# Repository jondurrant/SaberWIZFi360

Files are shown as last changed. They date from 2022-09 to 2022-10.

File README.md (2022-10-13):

# SaberWIZFi360
IoT Saber Wall Light using WizFi360-EVB-Pico

PIR and Switch activated wall light. Works as a group able to turn each other on and off via MQTT hub topics. 

Blog post and video talking about project coming soon.

# Hardware

+ WizFi360-EVB-Pico: RP2040 board with Wifi adapter for connectivity and control
+ 144, 1M WS2812B: The LED used to illuminate and animate the blade
+ Logic Level Shifter: Used to drive 5V signal to WS2812B
+ 1000uF Capacitor: Smooth out supply for the WS2812B strip
+ 330Ω Resistor: Signal connection to the WS2812B strip
+ 4x 75Ω (or 91Ω) Resistors for onboard LEDs
+ SPST Non-latching Switch: For turn on or off the blade
+ AM312: Small PIR sensor module
+ 100nF Cap: Power smoothing for the AM312 to prevent false detects
+ 100uF Cap: Power smoothing for the AM312 to prevent false detects
+ 5Amp Fuse and Holder: Main power fuse
+ 100℃ Thermal Fuse: Main power thermal fuse
+ RGB 5mm LED - To use as signal LED
+ Red 1.8mm LED - to use as a pulse LED against the device
+ 6V >5Amp Power Suppl
+ 1m White Acrylic 20mm Tube: The blade cover tube. White so it is diffusing the light
+ 3D Printed Parts: Handle and pommel are 3D printed

## Schema 
Schematic included in the schematic folder.

Warning: The LEDs will draw 4Amps of current. You should assure yourself that the circuit and wiring can safely deliver that current. 

## Case
Case is 3D printed in PLA. I've modelled the case and wall mounts for the case in OpenSCAD. The model and SLA files available in the 3dmodels folder.

## Blade
Blade is a 20mm x 3mm x 1000mm OPAL Acrylic Tube. You can find these on ebay, though I found ebay quite expensive. Bought mine from [The Clear Plastic Shop](https://clearplastictube.co.uk/opal-acrylic-tube) in the UK. 

# Software

## C++ - For Raspberry PICO
+ [CMSIS_5](https://github.com/ARM-software/CMSIS_5.git) - RELEASE 5.8.0 CMSIS Framework
+ [CMSIS-FreeRTOS]https://github.com/ARM-software/CMSIS-FreeRTOS.git() - RELEASE 10.5.6 CMSIS port of FreeRTOS
+ [CMSIS-Driver](https://github.com/ARM-software/CMSIS-Driver.git) - RELEASE 2.70 WizFi360 Driver
+ [IoT_Socket](https://github.com/MDK-Packs/IoT_Socket.git) - RELEASE 1.3.0 Socket framework
+ [coreMQTT](https://github.com/FreeRTOS/coreMQTT) - RELEASE 1.2.0 FreeRTOS MQTT library
+ [coreMQTT-Agent](https://github.com/FreeRTOS/coreMQTT-Agent) - FreeRTOS MQTT Agent library, using FreeRTOS tasks
+ [twinThingWizFi360](https://github.com/jondurrant/twinThingWizFi360) - Digital Twin library
+ [json-make](https://github.com/rafagafe/json-maker) - JSON creation used for the payload of all MQTT messages
+ [tiny-json](https://github.com/rafagafe/tiny-json) - JSON parser used for the payload parsing of all MQTT messages
+ [PicoLED](https://github.com/ForsakenNGS/PicoLED) - Used to drive the WS2812B LED via PIO

## Python -  Management Software
See the [LSaber1 project](https://github.com/jondurrant/LSaber1).

## Python Test Code
Some test code to interact with the api are included in py/test folder. They expect some environment variables to point to the MQTT hub and credentials.
+ MQTT_USER - Username and Client Id to connect to MQTT
+ MQTT_PASSWD - Password to authenticate against MQTT
+ MQTT_HOST - Hostname of MQTT server
+ MQTT_PORT - Port that MQTT is listen on, normally 1883

# Build and Deploy

##Clone project
```
git clone --recurse-submodules https://github.com/jondurrant/SaberWIZFi360
```
main.cpp include "Credentials.env" for the Wifi AP name and passwd, MQTT Host, Port, Username and password. I've not included this file in the repo. Please create one looking something like this:

``` C++
#define SID "SID"
#define PASSWD "PWD"

#define MQTTHOST "IP"
#define MQTTPORT 1883
#define MQTTUSER "jon"
#define MQTTPASSWD "PWD"
```

## To build C++:
``` bash
mkdir build
cd build
cmake ..
make
```

# Plug

For more on how I use a Raspberry PI to build, deploy code  and debug the Pico see my course on [Udemy](https://www.udemy.com/course/introduction-to-c-development-environment-for-raspberry-pico/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)

For more on FreeRTOS kernel development with the Pico or Pico W please see my course on [Udemy](https://www.udemy.com/course/freertos-on-rpi-pico/?referralCode=C5A9A19C93919A9DA294)

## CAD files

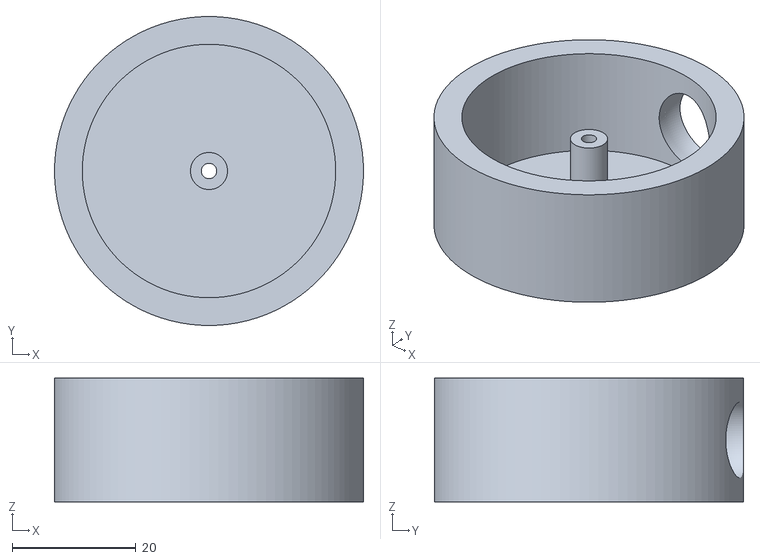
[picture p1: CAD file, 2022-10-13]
3dmodels/pummel.stl
50.0 x 50.0 x 20.0

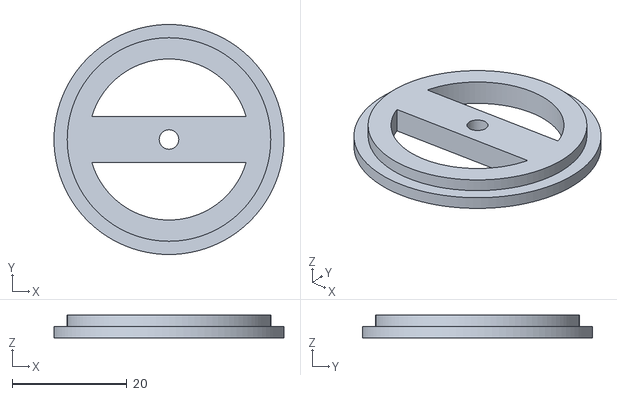
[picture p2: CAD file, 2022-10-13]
3dmodels/pummelInt.stl
40.0 x 40.0 x 4.00

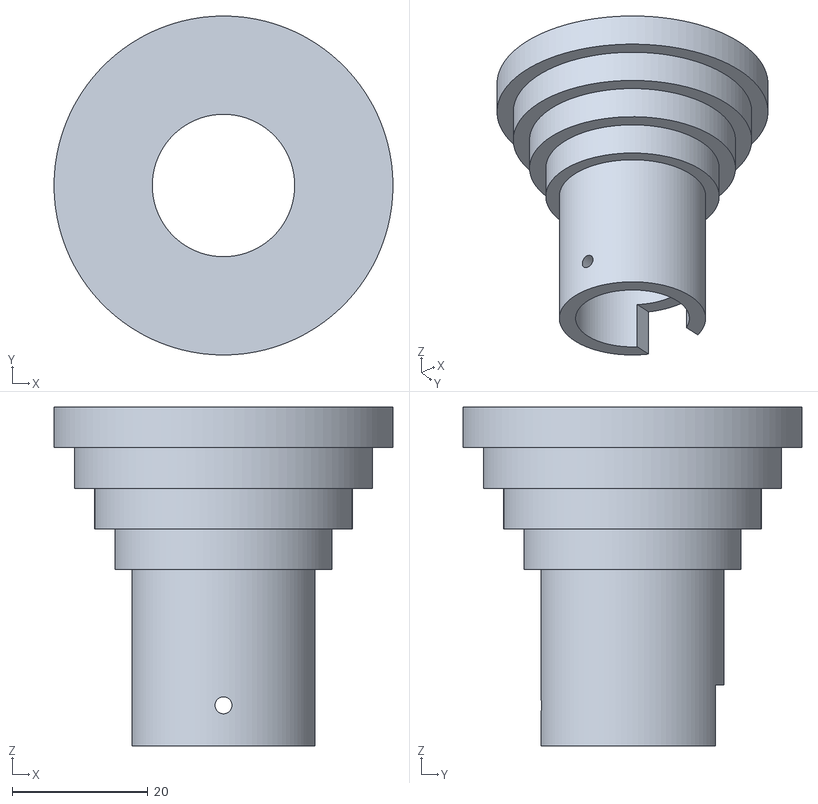
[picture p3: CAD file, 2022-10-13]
3dmodels/stem.stl
50.0 x 50.0 x 50.0

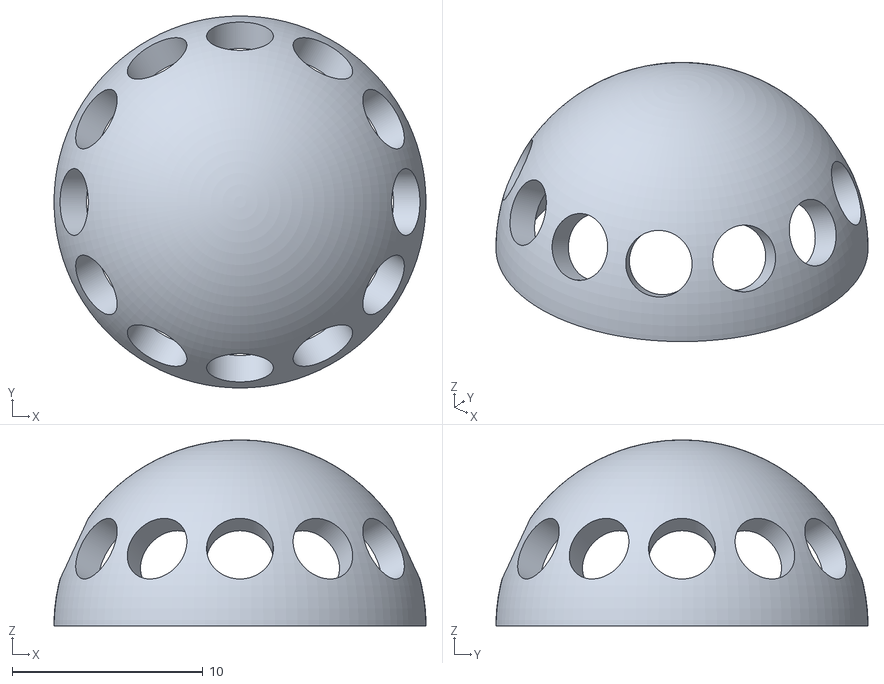
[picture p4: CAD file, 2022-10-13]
3dmodels/cap.stl
19.5 x 19.5 x 9.75

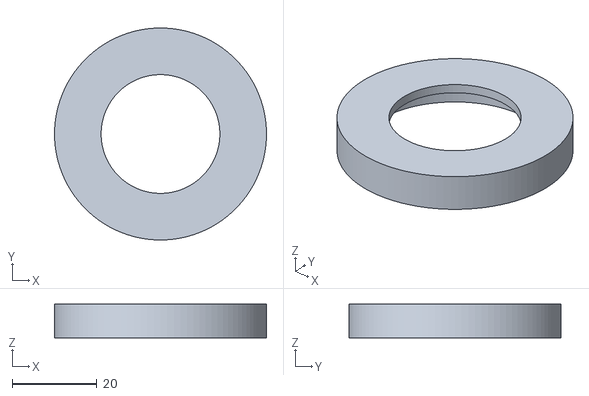
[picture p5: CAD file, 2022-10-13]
3dmodels/guardShort.stl
50.0 x 50.0 x 8.00

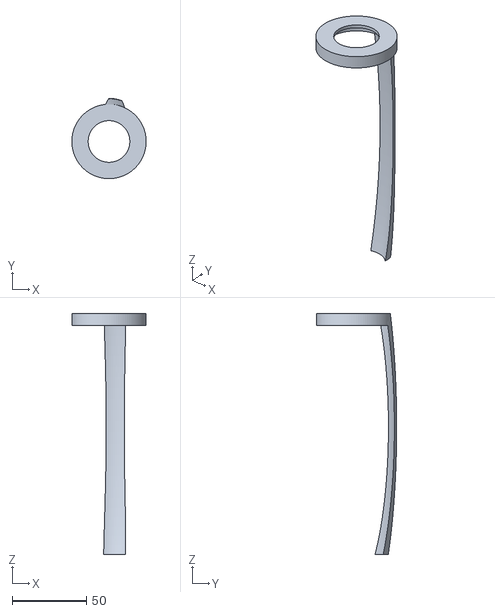
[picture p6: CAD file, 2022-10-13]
3dmodels/guard.stl
50.0 x 54.0 x 162.0

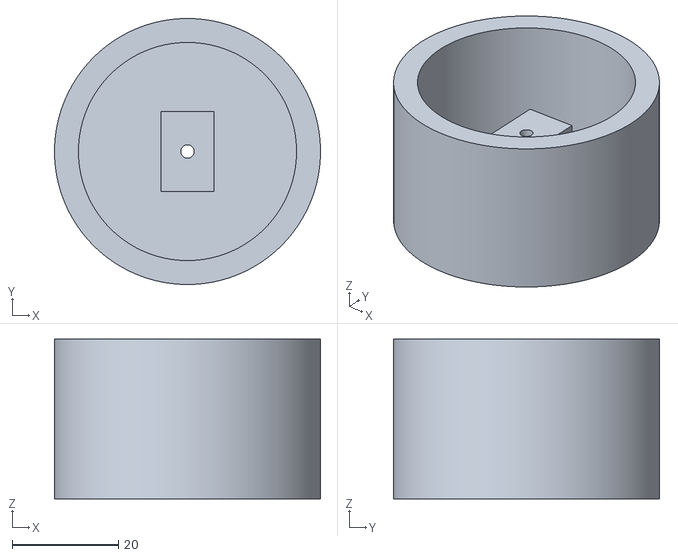
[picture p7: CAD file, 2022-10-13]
3dmodels/pummelHBS.stl
50.0 x 50.0 x 30.0

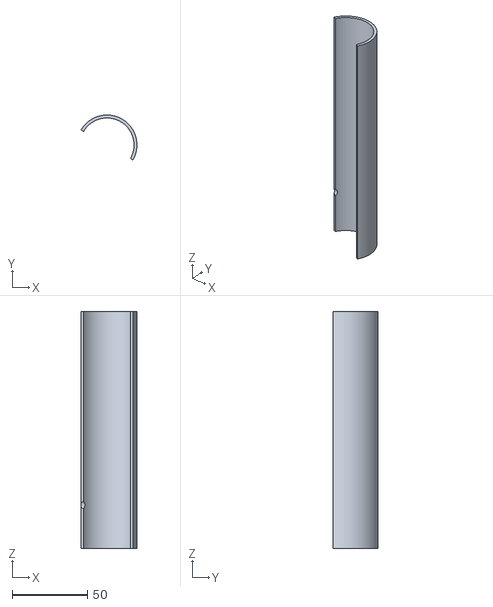
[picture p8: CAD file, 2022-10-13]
3dmodels/gripRear.stl
37.3 x 30.0 x 158.0

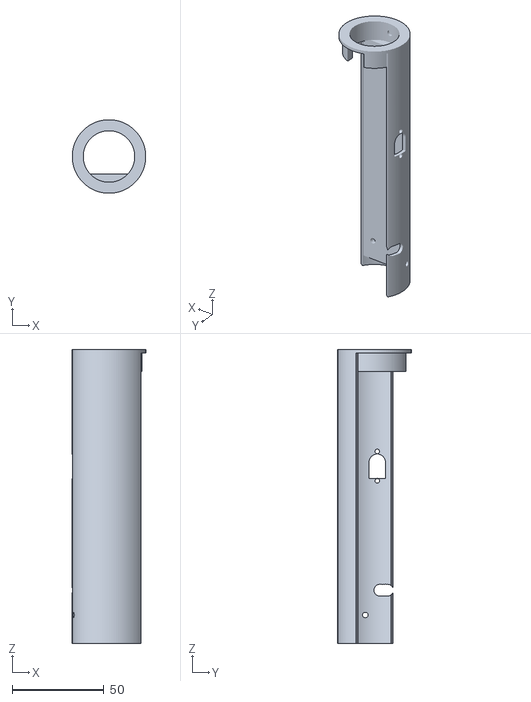
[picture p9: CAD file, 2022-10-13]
3dmodels/gripBack.stl
40.0 x 40.0 x 160.0

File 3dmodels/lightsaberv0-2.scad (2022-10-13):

//Fixings
M5=5.5;
M4=4.5;
M3=3.5;
M2=2.5;
M3INSERT=3.7;
M2INSERT=3.4;


//Blade
BladeDiam=23;//24;
BladeDiamTrue=19.5;
BladeLen=100; //Debug only
BladeThick=3;

CapCollar=2;

//Pico
PicoWid=21;
PicoLen=64;
PicoDep=19;

//PIZ
PIZWid=34;
PIZLen=72;
PIZDep=19;
PCBGrid=2.54;

//Stem
StemLen=50;
StemCollar=0;//5;
StemSegLen=6;
StemSegMaxDiam=50;
StemSegStep=6;

//Grip
GripLen=160; //Max print size is 170
GripDiam=40;//45;
GripOverlap=12;

//Pummel
PummelDiam=GripDiam+10;
PummelIntDiam = GripDiam + 1;
PummelLen=20;
PummelHBSLen=30;
PummelOverlap=5;
PowerWid=11.5;
PowerLen=9;


//PCB
PCBWidth=30.5;
PCBLen=135;
PCBBRy=3.9;
PCBBRx=7.35;
PCBBLx=16.51;//15.51;
PCBBLy=9.4;
PCBTRx=0;
PCBTRy=90.79;
PCBLEDy=12.5;
PCBLEDx=10;
PCBLEDz=5;
PCBSwitchD=5 ;
PCBSwitchY=23.5;
PCBSwitchX=7.6;
PCBSwitchZ=15;//12;
PCBSwitchL=20;
PCBCapX=12;
PCBCapY=114;
PCBCapL=20;
PCBCapZ=PCBCapL/2;
PCBCapD=10.2;
PCBOffz=10;
PCBOffy=-10;



THICK=2;

$fn=200;


/*
Blade();
Pico();
PIZ();
*/
//Blade();
//PCB();
//PIR();

    
//BladeCap();

//Stem();
//GripBack();
//PummelInt();
//Pummel();
PummelHBS();
//translate([5,10,0]) GripFront();
//GripFront();

//Guard();
//GuardShort();

//MountBottom();
//MountTop();



//Test print
/*
difference(){
    GripBack();
    translate([0,0,GripLen*(-0.85)])
        cube([PummelDiam, PummelDiam, GripLen], center=true);
}
*/




module Blade(){
    color("blue")
    translate([0,0,BladeLen/2]){
        difference(){
            cylinder(d=BladeDiam, h=BladeLen, center=true);
            cylinder(d=BladeDiam-(BladeThick*2), h=BladeLen+10, center=true);
        }
        
    }
}

module BladeCap(){
    inner = BladeDiamTrue-(BladeThick);
    translate([0,0,BladeLen]){
        //Half hollow Sphere
        difference(){
            sphere(d=BladeDiamTrue, $fn=100);
            sphere(d=inner);
            translate([0,0,BladeDiamTrue/(-2)]){
                cube([BladeDiamTrue+10, BladeDiamTrue+10, BladeDiamTrue], center=true);
            }
            
            
           for (x=[0:30:360]){
               rotate([0,0,x]){
                   rotate([0,65,0])
                      cylinder(d=M3, h=BladeThick*10, center=true);
               }
           }
  
            
        }
        //Connection collar
        /*
        difference(){
            cylinder(d=inner, h=CapCollar*2, center=true);
            cylinder(d=inner-(THICK*2), h=CapCollar*4, center=true);
        }
        */
    }
}

module Stem(){
    //Inner Tube
    translate([0,0,StemLen/(-2)]){
        difference(){
            cylinder(d=BladeDiam+(THICK*2), h=StemLen, center=true);
            cylinder(d=BladeDiam-(THICK), h=StemLen+10, center=true);
            translate([0,0,(StemLen/2)-(StemCollar/2)]){
                cylinder(d=BladeDiam, h=StemCollar, center=true);
            }
            
            //Coupline
            CoupZ=StemLen/(-2) + (GripOverlap/2);
            translate([0, 0, CoupZ]){
                //Hole
                rotate([90,0,0]){
                    cylinder(d=M2, h=BladeDiam+(THICK*4), center=true);
                }
                //Loose top
                translate([0, (BladeDiam+(THICK*2))/2, THICK*(-1)]){
                    //cube([BladeDiam+(THICK*2), BladeDiam+(THICK*2), GripOverlap-THICK], center=true);
                    cube([BladeDiam/2, BladeDiam+(THICK*2), GripOverlap-THICK], center=true);
                }
            }
        }
    }
    //Steps
    difference(){
        translate([0,0,StemSegLen/2]){
            for(i=[0:4]){
                translate([0, 0, (StemSegLen*(i+1))/(-1)]){
                    cylinder(d=StemSegMaxDiam-(StemSegStep*i), h=StemSegLen, center=true);
                }
            }
        }
        //Hole
        translate([0,0,StemLen/(-2)]){
            cylinder(d=BladeDiam, h=StemLen+10, center=true);
        }   
    }
}

function picoZ()=(StemLen + ((PicoLen+(THICK*4)) / (2)))* (-1) ;

module Pico(){
    z=picoZ();
    translate([0,0,z]){
        color("lightgrey"){
            cube([PicoWid, PicoDep, PicoLen], center=true);
        }
    }
}

module PIZ(){
    z=picoZ() - PIZLen ;
    translate([0,0,z]){
        color("lightGreen"){
            cube([PIZWid, PIZDep, PIZLen], center=true);
        }
    }
}


module GripBack(){
    difference(){
        GripTube();
        rotate([0,0,-30]){
            translate([0,GripDiam/2, gripTubeZ()-THICK]){
                cube([GripDiam+10,GripDiam,GripLen ], center=true);
            }
        }
    }
    stemCoupling();
}

module GripFront(){
    intersection(){
        difference(){
            GripTube();
            translate([0,0,gripTubeZ()]){
                cylinder(d=GripDiam - (THICK*2), h=GripLen+10, center=true);
            }
            rotate([0, 0, -30]){
                translate([0,GripDiam/(-2), gripTubeZ()]){
                    cube([GripDiam+10,GripDiam,GripLen+10 ], center=true);
                }
            }
            
            /*
            //Switch hole
            translate([0,PCBOffy,gripTubeZ()]){
                for(i=[-2:1:2]){
                    translate([PCBWidth/-2, PCBSwitchZ + i, PCBLen/-2-5.5+PCBSwitchY]){
                        rotate([0,90,0]){
                            cylinder(d=PCBSwitchD+1,h=20,center=true);
                        }
                    }
                }
            }
            */
        }
        
        rotate([0, 0, -30]){
            translate([0,GripDiam/2, gripTubeZ()-THICK]){
                cube([GripDiam+10,GripDiam,GripLen ], center=true);
            }
        }
    }
}
    
function gripTubeZ() = (StemLen + GripLen/2 - GripOverlap) *( -1);
module GripTube(){
    z=gripTubeZ();
    translate([0,0,z]){
        difference(){
            cylinder(d=GripDiam, h=GripLen, center=true);
            translate([0,0,THICK*(-1)]){
                cylinder(d=GripDiam - (THICK*2), h=GripLen, center=true);
            }
            //Stem Hole
            cylinder(d=BladeDiam+(THICK*2.5), h=GripLen+10, center=true);
            
            //LED hole
            translate([PCBWidth/-2, PCBLEDz*(-1), PCBLen/-2-9.5+PCBLEDy]){
                rotate([0,90,0]){
                    cylinder(d=3,h=20,center=true);
                }
            }
            
            //Switch hole
            translate([PCBWidth/-2, PCBSwitchZ+PCBOffy, PCBLen/-2-7+PCBSwitchY]){
                for(i=[-2:1:2]){
                    translate([0, i, 0]){
                        rotate([0,90,0]){
                            cylinder(d=PCBSwitchD+1.5,h=20,center=true);
                        }
                    }
                }
            }
            
            //PowerHole
            translate([PCBWidth/-2, -4.5, PCBLen/2-5]){
                translate([-5, 0, PowerSocketY*(-1)]){
                    rotate([90,0,0])
                        PowerSocketHole();
                }
            }
        }
    }
    
    stemCoupling();
    
    
    //PCB Mount
    translate([0,0,z-(GripOverlap/2)]){
        difference(){
            //PCB plate
            cylinder(d=GripDiam, h=GripLen-(GripOverlap), center=true);
            cube([GripDiam, PIZDep, GripLen], center=true);
            translate([0,GripDiam/2,0]){
                cube([GripDiam+10, GripDiam, GripLen+10], center=true);
            }
            translate([0,0,PCBLen/(-2)-5]){
                cube([GripDiam, GripDiam, 10], center=true);
            }
            
            //Mounting Holes
            translate([PCBWidth/-2,0, PCBLen/-2-1.5]){
                translate([PCBBRx,0,PCBBRy]){
                    rotate([90,0,0]){
                        cylinder(d=M2INSERT, h=BladeDiam+(THICK*4), center=true);
                    }
                    translate([PCBBLx,0, PCBBLy]){
                        rotate([90,0,0]){
                            cylinder(d=M2INSERT, h=BladeDiam+(THICK*4), center=true);
                        }
                    }
                    translate([PCBTRx,0, PCBTRy]){
                       rotate([90,0,0]){
                            cylinder(d=M2INSERT, h=BladeDiam+(THICK*4), center=true);
                        }
                    }
                }
            }
            
            
            /*
            //PCB Weight Holes
            pcbCountX=GripDiam/PCBGrid/2-2;
            pcbCountY=(GripLen-GripOverlap)/PCBGrid/2;
            for (y=[0:5:pcbCountY]){
                for (j=[-1,1]){
                    translate([0, 0, y*j*PCBGrid]){
                        for (x=[0:3:pcbCountX]){
                            for (i=[-1,1]){
                                translate([x*i*PCBGrid,0,0]){
                                    rotate([90,0,0]){
                                        cylinder(d=M2INSERT, h=BladeDiam+(THICK*4), center=true);
                                    }
                                }
                            }
                        }
                    }
                }
            }
            */
            
        }
    }
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

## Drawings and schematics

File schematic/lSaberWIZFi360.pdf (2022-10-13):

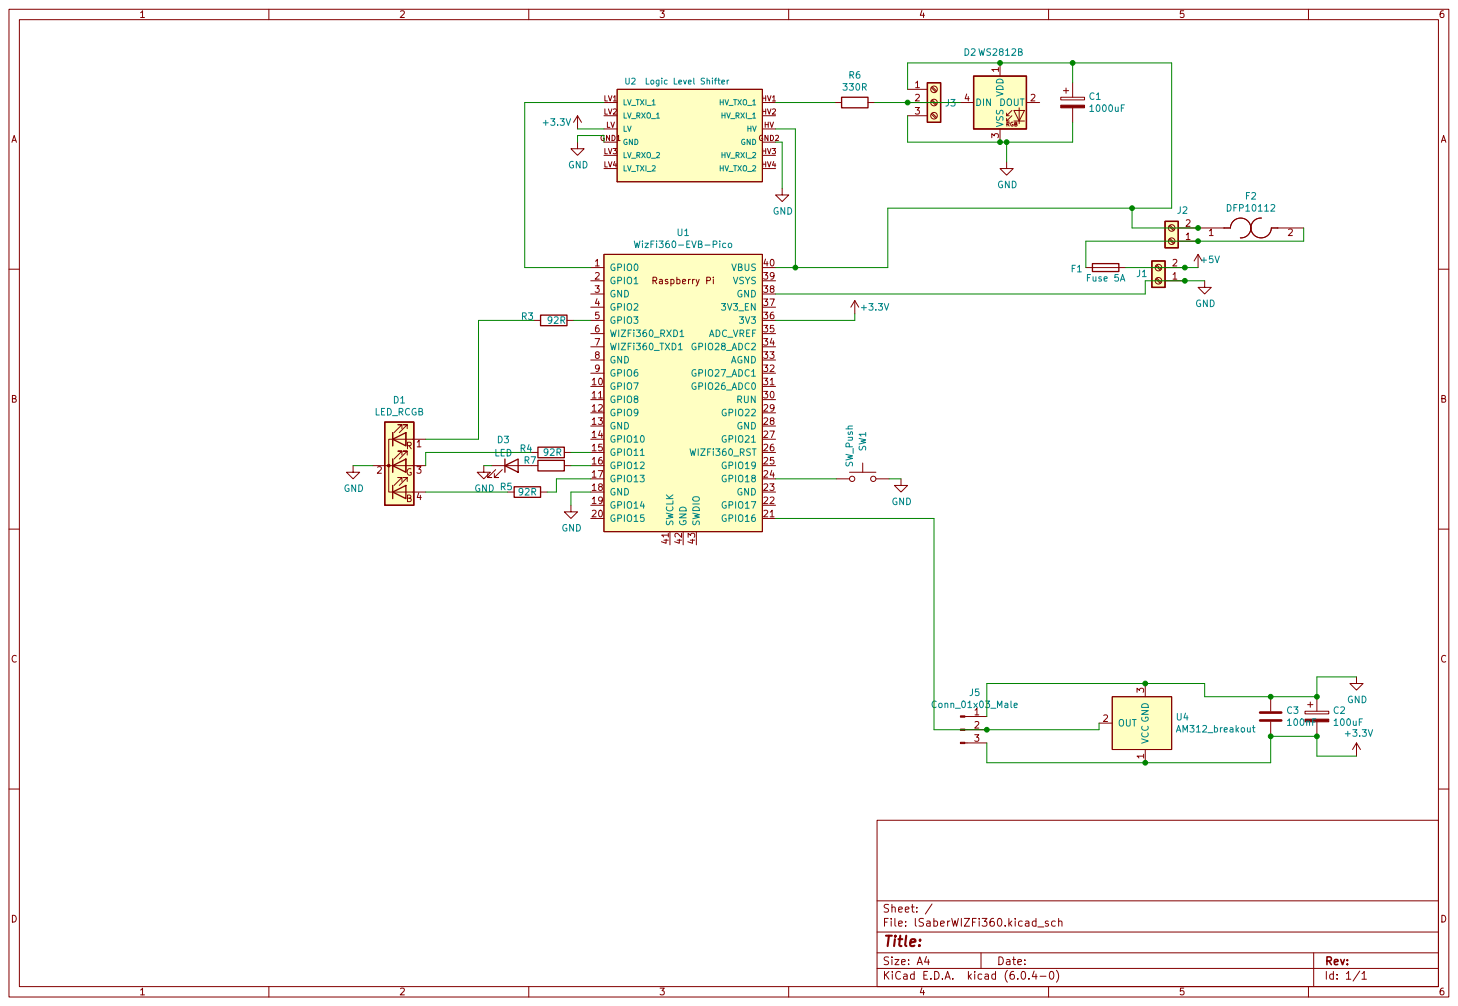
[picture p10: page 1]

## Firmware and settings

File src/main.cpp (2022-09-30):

#include <stdio.h>
#include "pico/stdlib.h"
#include "FreeRTOS.h"
#include "task.h"
#include <array>
#include <stdint.h>


#include <WatchdogBlinkAgent.h>

#include "pico/multicore.h"

#include <PicoLed.hpp>




//Local include file not in git repository, defining the credentials
#include "Credentials.env"
#ifndef SID
#define SID "sid"
#define PASSWD "passwd"
#endif
#ifndef MQTTHOST
#define MQTTHOST "MQTTSERVER"
#define MQTTPORT 1883
#define MQTTUSER "USER"
#define MQTTPASSWD "PASSWD"
#endif


#include "MQTTAgent.h"
#include "MQTTRouterPing.h"
#include "MQTTRouterTwin.h"

#include <WifiHelper.h>

#include "StateExample.h"
#include "ExampleAgentObserver.h"
#include "RGBLEDMgr.h"
#include "RGBLEDAgent.h"
#include "SaberState.h"
#include "BladeMgr.h"
#include "BladeStateAgent.h"
#include "MQTTRouterSaber.h"



#define RED_PAD  3
#define GRN_PAD 13
#define BLU_PAD 11
#define LED_PAD 12

void core1_entry() {
	BladeMgr blade;
	blade.loopForever();

}

void runTimeStats( ){
	TaskStatus_t *pxTaskStatusArray;
	volatile UBaseType_t uxArraySize, x;
	unsigned long ulTotalRunTime, ulStatsAsPercentage;

   /* Take a snapshot of the number of tasks in case it changes while this
   function is executing. */
   uxArraySize = uxTaskGetNumberOfTasks();

   /* Allocate a TaskStatus_t structure for each task.  An array could be
   allocated statically at compile time. */
   pxTaskStatusArray = (TaskStatus_t *)pvPortMalloc( uxArraySize * sizeof( TaskStatus_t ) );

   if( pxTaskStatusArray != NULL ){
      /* Generate raw status information about each task. */
      uxArraySize = uxTaskGetSystemState( pxTaskStatusArray,
                                 uxArraySize,
                                 &ulTotalRunTime );

      /* For percentage calculations. */
      ulTotalRunTime /= 100UL;

	 /* For each populated position in the pxTaskStatusArray array,
	 format the raw data as human readable ASCII data. */
	 for( x = 0; x < uxArraySize; x++ )
	 {
		/* What percentage of the total run time has the task used?
		This will always be rounded down to the nearest integer.
		ulTotalRunTimeDiv100 has already been divided by 100. */
		if( ulTotalRunTime > 0 ) {
			ulStatsAsPercentage =
				  pxTaskStatusArray[ x ].ulRunTimeCounter / ulTotalRunTime;
		} else {
			ulStatsAsPercentage = 0;
		}

		if( ulStatsAsPercentage > 0UL )
		{
		   printf("%s tt:%l utt:%l u%%r\n",
							 pxTaskStatusArray[ x ].pcTaskName,
							 pxTaskStatusArray[ x ].ulRunTimeCounter,
							 ulStatsAsPercentage );
		}
		else
		{
		   /* If the percentage is zero here then the task has
		   consumed less than 1% of the total run time. */
		   printf("%s tt:%l utt<1%% bp:%d cp:%d state:%d\n",
							 pxTaskStatusArray[ x ].pcTaskName,
							 pxTaskStatusArray[ x ].ulRunTimeCounter,
							 pxTaskStatusArray[ x ].uxBasePriority,
							 pxTaskStatusArray[ x ].uxCurrentPriority,
							 pxTaskStatusArray[ x ].eCurrentState
							 );
		}
	 }

      /* The array is no longer needed, free the memory it consumes. */
      vPortFree( pxTaskStatusArray );
   }else {
 	  printf("Malloc failed\n");
   }
}




void
init_thread(void* pvParameters) {
	char mqttTarget[] = MQTTHOST;
	uint16_t mqttPort = MQTTPORT;
	char mqttUser[] = MQTTUSER;
	char * pMqttUser = mqttUser;
	char mqttPwd[] = MQTTPASSWD;
	char * pMqttPwd = mqttPwd;
	char macs[15];
	bool ssl= false;


	WatchdogBlinkAgent watchdog(LED_PAD);
	watchdog.start(tskIDLE_PRIORITY+1);

	MQTTRouterSaber mqttRouter;
	SaberState state;

	MQTTAgent mqttAgent;
	BladeStateAgent xTwin;
	MQTTPingTask xPing;

	RGBLEDAgent xLed(RED_PAD, GRN_PAD, BLU_PAD);
	xLed.start(tskIDLE_PRIORITY+1);
	xLed.set(RGBModeOn, 0xFF, 0xFF, 0xFF);
	RGBLEDMgr xLedMgr(&xLed);

	//Connect to WiFi
	printf("Connecting to SID %s\n", SID);
	if (WifiHelper::connectToAp(SID, PASSWD)){
		char ips[16];
		WifiHelper::getIPAddressStr(ips);
		printf("WIFI IP %s\n", ips);
		if (WifiHelper::getMACAddressStr(macs)){
			printf("MAC %s\n", macs);
			if (strcmp(mqttUser, "MAC") == 0){
				pMqttUser = macs;
			}
			if (strcmp(mqttPwd, "MAC") == 0){
				pMqttPwd = macs;
			}
		} else {
			printf("MAC NOT AVAILABLE\n");
		}
		WifiHelper::syncRTCwithSNTP();


		//Set up the credentials so we have an ID for our thing
		mqttAgent.credentials(pMqttUser, pMqttPwd);
		mqttRouter.init(mqttAgent.getId(), &mqttAgent);

		//Twin agent to manage the state
		xTwin.setStateObject(&state);
		xTwin.setMQTTInterface(&mqttAgent);
		xTwin.start(tskIDLE_PRIORITY+1);
		xTwin.setTopics(mqttRouter.getGroupTopicOn(), mqttRouter.getGroupTopicOff());

		//Start up a Ping agent to mange ping requests
		xPing.setInterface(&mqttAgent);
		xPing.start(tskIDLE_PRIORITY+1);

		//Give the router the twin and ping agents
		mqttRouter.setTwin(&xTwin);
		mqttRouter.setPingTask(&xPing);

		//Setup and start the mqttAgent
		mqttAgent.setObserver(&xLedMgr);
		mqttAgent.setRouter(&mqttRouter);

#ifdef MQTTSSL
		ssl = true;
#endif
		mqttAgent.mqttConnect(mqttTarget, mqttPort, true, ssl);

		mqttAgent.start(tskIDLE_PRIORITY+1);

	} else {
		xLed.set(RGBModeSlow, 0xFF, 0xff, 0xff);
		printf("ERROR: WIFI Connection failed\n");
	}

	//xLed.start(tskIDLE_PRIORITY);

    for (;;){
    	vTaskDelay(5000);

    	if (! WifiHelper::isJoined()){
    		while (! WifiHelper::connectToAp(SID, PASSWD)){
    			vTaskDelay(5000);
    		}
    		char ips[16];
			WifiHelper::getIPAddressStr(ips);
			printf("WIFI IP %s\n", ips);
    	}

    	//runTimeStats();
    }
}



int main() {

	stdio_init_all();

	sleep_ms(3000);
	printf("******GO******\n");

	multicore_reset_core1 ();
	multicore_launch_core1(core1_entry);


    BaseType_t atReturned;
	TaskHandle_t atHandle = NULL;

	atReturned = xTaskCreate(
					init_thread,
					"Init task",
					1024,
					( void * ) 1,
					tskIDLE_PRIORITY+1,
					&atHandle );




    vTaskStartScheduler();
    while(1)
    {
        configASSERT(0);    /* We should never get here */
    }

}

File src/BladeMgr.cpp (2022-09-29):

/*
 * BladeMgr.cpp
 *
 *  Created on: 3 Dec 2021
 *      Author: jondurrant
 */

#include "BladeMgr.h"
#include "BladeRequest.h"

#include "BladeSeqBinary.h"
#include "BladeSeqNewHope.h"
#include "BladeSeqWand.h"
#include "BladeSeqCandle.h"
#include "BladeSeqSpark.h"
#include "BladeSeqAlert.h"
#include "BladeSeqBright.h"

#include "hardware/gpio.h"
#include <stdio.h>

BladeMgr * BladeMgr::pSelf = NULL;

BladeMgr::BladeMgr(uint8_t pirPin, uint8_t switchPin) {
	pSelf = this;
	xPirPin = pirPin;
	xSwitchPin = switchPin;

	//Set up PIR
	gpio_init(xPirPin);
	gpio_set_dir(xPirPin, GPIO_IN);
	//gpio_pull_down(xPirPin);
	gpio_set_irq_enabled_with_callback(xPirPin,
		GPIO_IRQ_EDGE_RISE,
		true,
		gpioCallback
	);

	//Set Switch
	gpio_init(xSwitchPin);
	gpio_set_dir(xSwitchPin, GPIO_IN);
	gpio_pull_up (xSwitchPin);
	gpio_set_irq_enabled_with_callback(xSwitchPin,
		GPIO_IRQ_EDGE_RISE | GPIO_IRQ_EDGE_FALL,
		true,
		gpioCallback
	);

	initSeqs();
}

BladeMgr::~BladeMgr() {
	// TODO Auto-generated destructor stub
}


void BladeMgr::loopForever(){
	BladeRequest req;
	uint32_t mesg;


	ledStrip.setBrightness(255);

	ledStrip.fill( PicoLed::RGB(0, 0, 0) );
	ledStrip.show();

	for(;;){
		if (req.readFromQueue()){
			switch(req.getReq()){
			case BladeDRGB: {
				setColour(true, req.getRed(),
						req.getGreen(),
						req.getBlue()
						);

				//printf("\nBladeMgr colour\n");

				break;
			}
			case BladeNRGB: {
				setColour(false, req.getRed(),
						req.getGreen(),
						req.getBlue()
						);

				//printf("\nBladeMgr colour\n");

				break;
			}
			case BladeOn: {
				turnOn(true, BladeSourceControl);
				break;
			}
			case BladeOff: {
				turnOff(true, BladeSourceControl);
				break;
			}
			case BladeDSeq: {
				setSeq(true, req.getSeq());
				break;
			}
			case BladeNSeq: {
				setSeq(false, req.getSeq());
				break;
			}
			case BladeDay: {
				xDay = true;
				break;
			}
			case BladeNight: {
				xDay = false;
				break;
			}
			case BladeTimer: {
				xOffTimeMS = req.getTimer() * 1000;
				break;
			}
			}
		}

		if (xTimeTurnedOn != 0){
			uint32_t timeOn = to_ms_since_boot(get_absolute_time()) - xTimeTurnedOn;
			if (timeOn > xOffTimeMS){
				turnOff(false, BladeSourceTimeout);
				xTimeTurnedOn = 0;
			}
		}

		if (xDay){
			getBladeSeqs()->tick(&xDayColour, &ledStrip, LEDS_LENGTH);
		} else {
			getBladeSeqs()->tick(&xNightColour, &ledStrip, LEDS_LENGTH);
		}

	}


}

void BladeMgr::turnOn(bool remote,  BladeSourceType source){
	BladeRequest req;

	if (!isOn()){
		if (xDay){
			getBladeSeqs()->on(&xDayColour, &ledStrip, LEDS_LENGTH);
		} else {
			getBladeSeqs()->on(&xNightColour, &ledStrip, LEDS_LENGTH);
		}
	}



	xTimeTurnedOn = to_ms_since_boot(get_absolute_time());

	if (!remote){
		req.setReq(BladeOn);
		req.setSource(source);
		req.writeToQueue();
	}
	//printf("\nBladeMgr on\n");
	xOn = true;
}

void BladeMgr::turnOff(bool remote,  BladeSourceType source){
	BladeRequest req;

	if (isOn()){
		if (xDay){
			getBladeSeqs()->off(&xDayColour, &ledStrip, LEDS_LENGTH);
		} else {
			getBladeSeqs()->off(&xNightColour, &ledStrip, LEDS_LENGTH);
		}
	}



	xTimeTurnedOn = 0;

	if (!remote){
		req.setReq(BladeOff);
		req.setSource(source);
		req.writeToQueue();
	}
	//printf("\nBladeMgr off\n");

	xOn = false;
}



void BladeMgr::setColour( bool day, uint8_t r, uint8_t g, uint8_t b){
	if (day){
		xDayColour.set(r, g, b);
	} else {
		xNightColour.set(r, g, b);
	}
}


void BladeMgr::gpioCallback (uint gpio, uint32_t events){
	BladeMgr::pSelf->handleGPIO(gpio, events);
}


void BladeMgr::handleGPIO (uint gpio, uint32_t events){
	if (gpio == xPirPin){
		if ((events & 0x08) > 0){
			if (gpio_get(xPirPin))
				turnOn(false, BladeSourcePIR);
		}
	}


	if (gpio == xSwitchPin){
		if ((events & GPIO_IRQ_EDGE_FALL) > 0){
			xSwitchTime = to_ms_since_boot(get_absolute_time ());
		}
		if ((events & GPIO_IRQ_EDGE_RISE) > 0){
			uint32_t t = to_ms_since_boot(get_absolute_time ()) - xSwitchTime;
			if ((t < 100) || (t > 5000)){
				return;
			} else if (t < 1000){
				handleShortPress();
			} else {
				handleLongPress();
			}
		}
	}
}


void BladeMgr::handleShortPress(){
	if (isOn()){
		turnOff(false, BladeSourceSwitch);
	} else {
		turnOn(false, BladeSourceSwitch);
	}
}

void BladeMgr::handleLongPress(){
	//turnOn();
	xDay = ! xDay;
	turnOn(false, BladeSourceSwitch);
}

void BladeMgr::initSeqs(){
	xpBladeSeqs[0] = new BladeSeqAlert;
	xpBladeSeqs[1] = new BladeSeqNewHope;
	xpBladeSeqs[2] = new BladeSeqWand;
	xpBladeSeqs[3] = new BladeSeqCandle;
	xpBladeSeqs[4] = new BladeSeqSpark;
	xpBladeSeqs[5] = new BladeSeqBinary;
	xpBladeSeqs[6] = new BladeSeqBright;
	xDaySeqInd = 6;
	xNightSeqInd = 0;
}


BladeSeqInterface *  BladeMgr::getBladeSeqs(){
	if (xDay){
		return xpBladeSeqs[xDaySeqInd];
	} else {
		return xpBladeSeqs[xNightSeqInd];
	}
}

bool BladeMgr::isOn(){
	return xOn;
}

void BladeMgr::setSeq(bool day, uint8_t seq){
	if (seq < BLADE_SEQ_COUNT) {
		if (day){
			xDaySeqInd = seq;
		} else {
			xNightSeqInd = seq;
		}
	}
}
